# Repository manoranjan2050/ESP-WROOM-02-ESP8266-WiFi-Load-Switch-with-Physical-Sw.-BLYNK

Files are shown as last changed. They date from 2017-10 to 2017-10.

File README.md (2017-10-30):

# ESP-WROOM-02-ESP8266-WiFi-Load-Switch-with-Physical-Sw.-BLYNK
ESP8266 WiFi Mobile On-Off with Sync. Physical Sw. BLYNK App.

ESP-WROOM-02 BLYNK ONE Switch is a WiFi Load switch for Light Bulb, Fan, A/C etc. 
Synchronized Physical switch change button state on BLYNK server.

IMAGE ALT TEXT HERE (https://www.youtube.com/watch?v=g_l_Oe-BA2k) 

For instructions and setup. http://esp8266.signal.com.tr/

for PCB and PCBA Production https://www.pcbway.com/

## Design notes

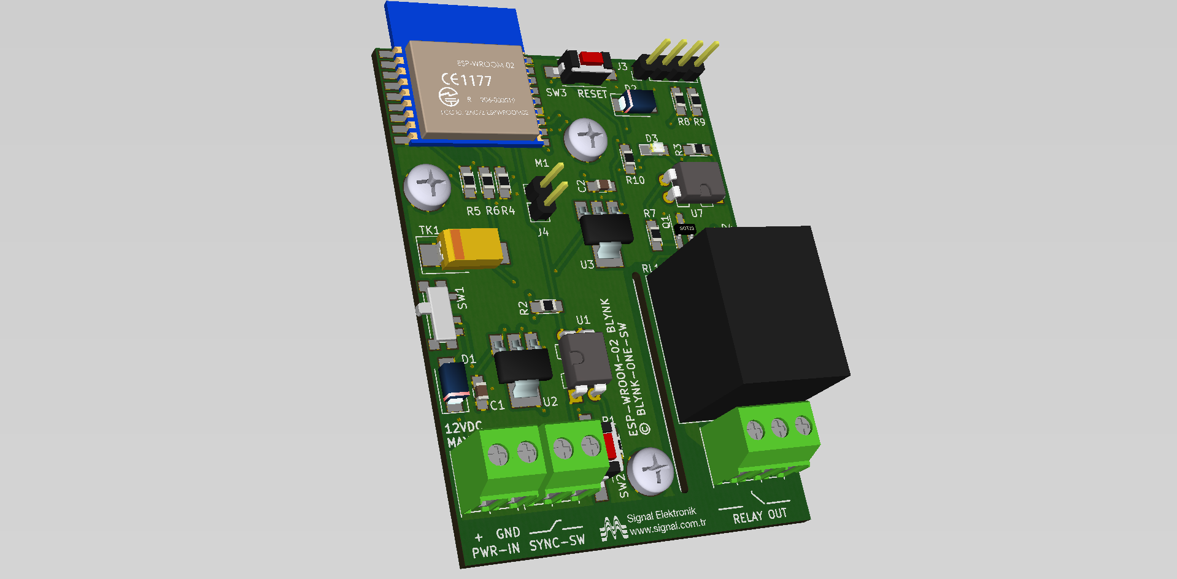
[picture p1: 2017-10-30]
esp-role-blynk/esp-relay-blynk.png

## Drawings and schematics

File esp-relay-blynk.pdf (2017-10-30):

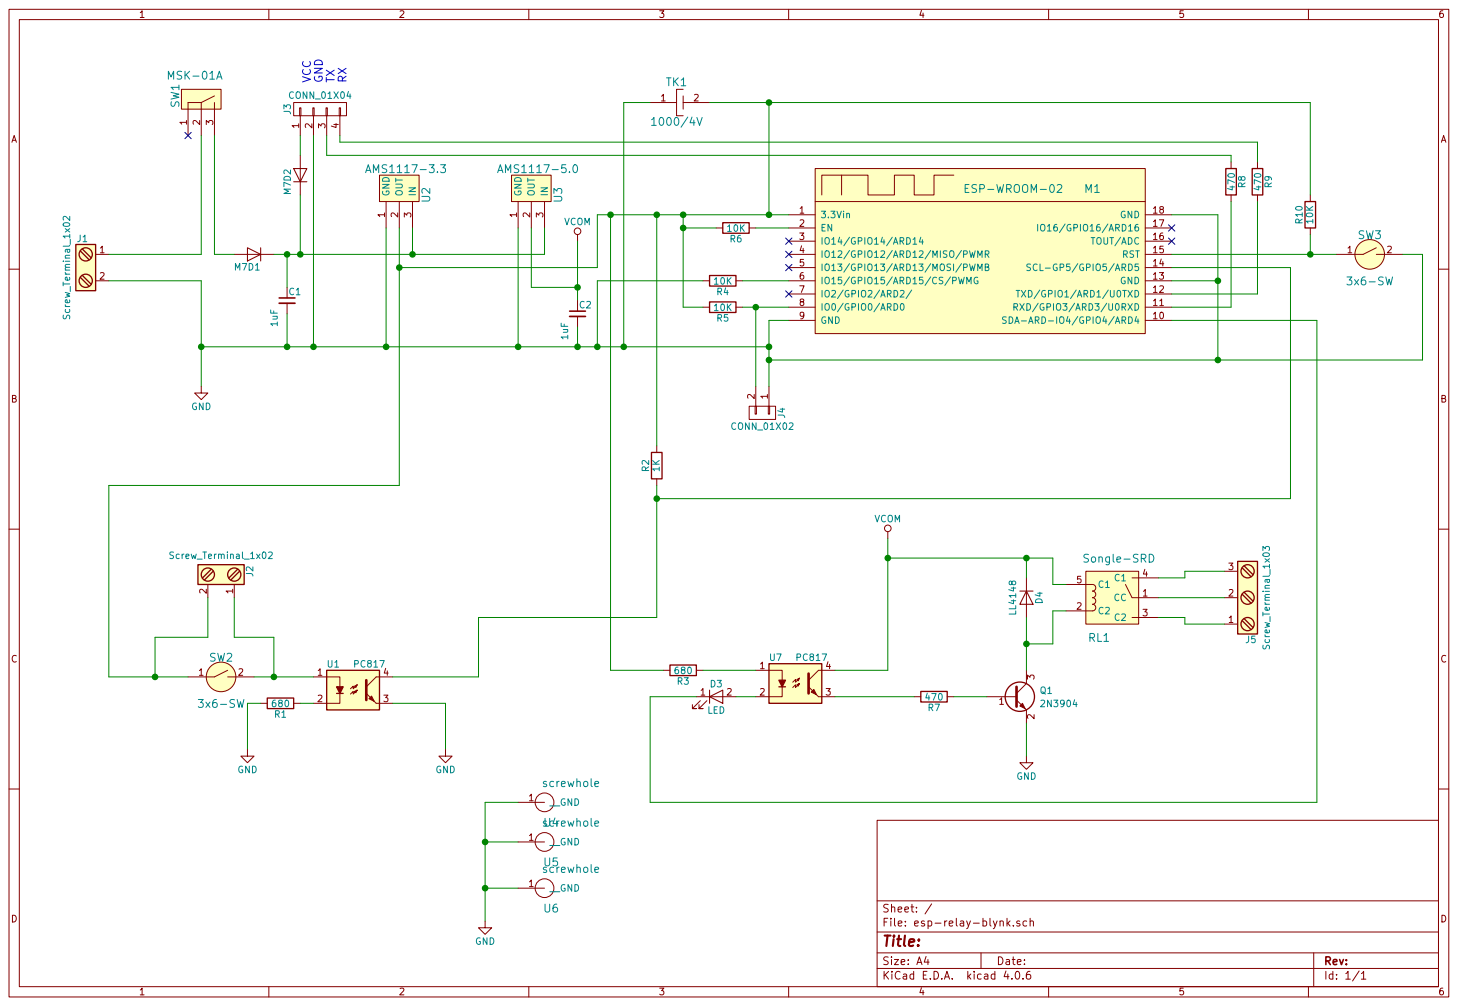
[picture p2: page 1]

1 J4 CONN_01X02 VCOM 470 R8 470 R9 CC 1 C2 2 C2 3 C1 4 C1 5 RL1 Songle-SRD

File: esp-relay-blynk.sch Sheet: /
Id: 1/1 Title:

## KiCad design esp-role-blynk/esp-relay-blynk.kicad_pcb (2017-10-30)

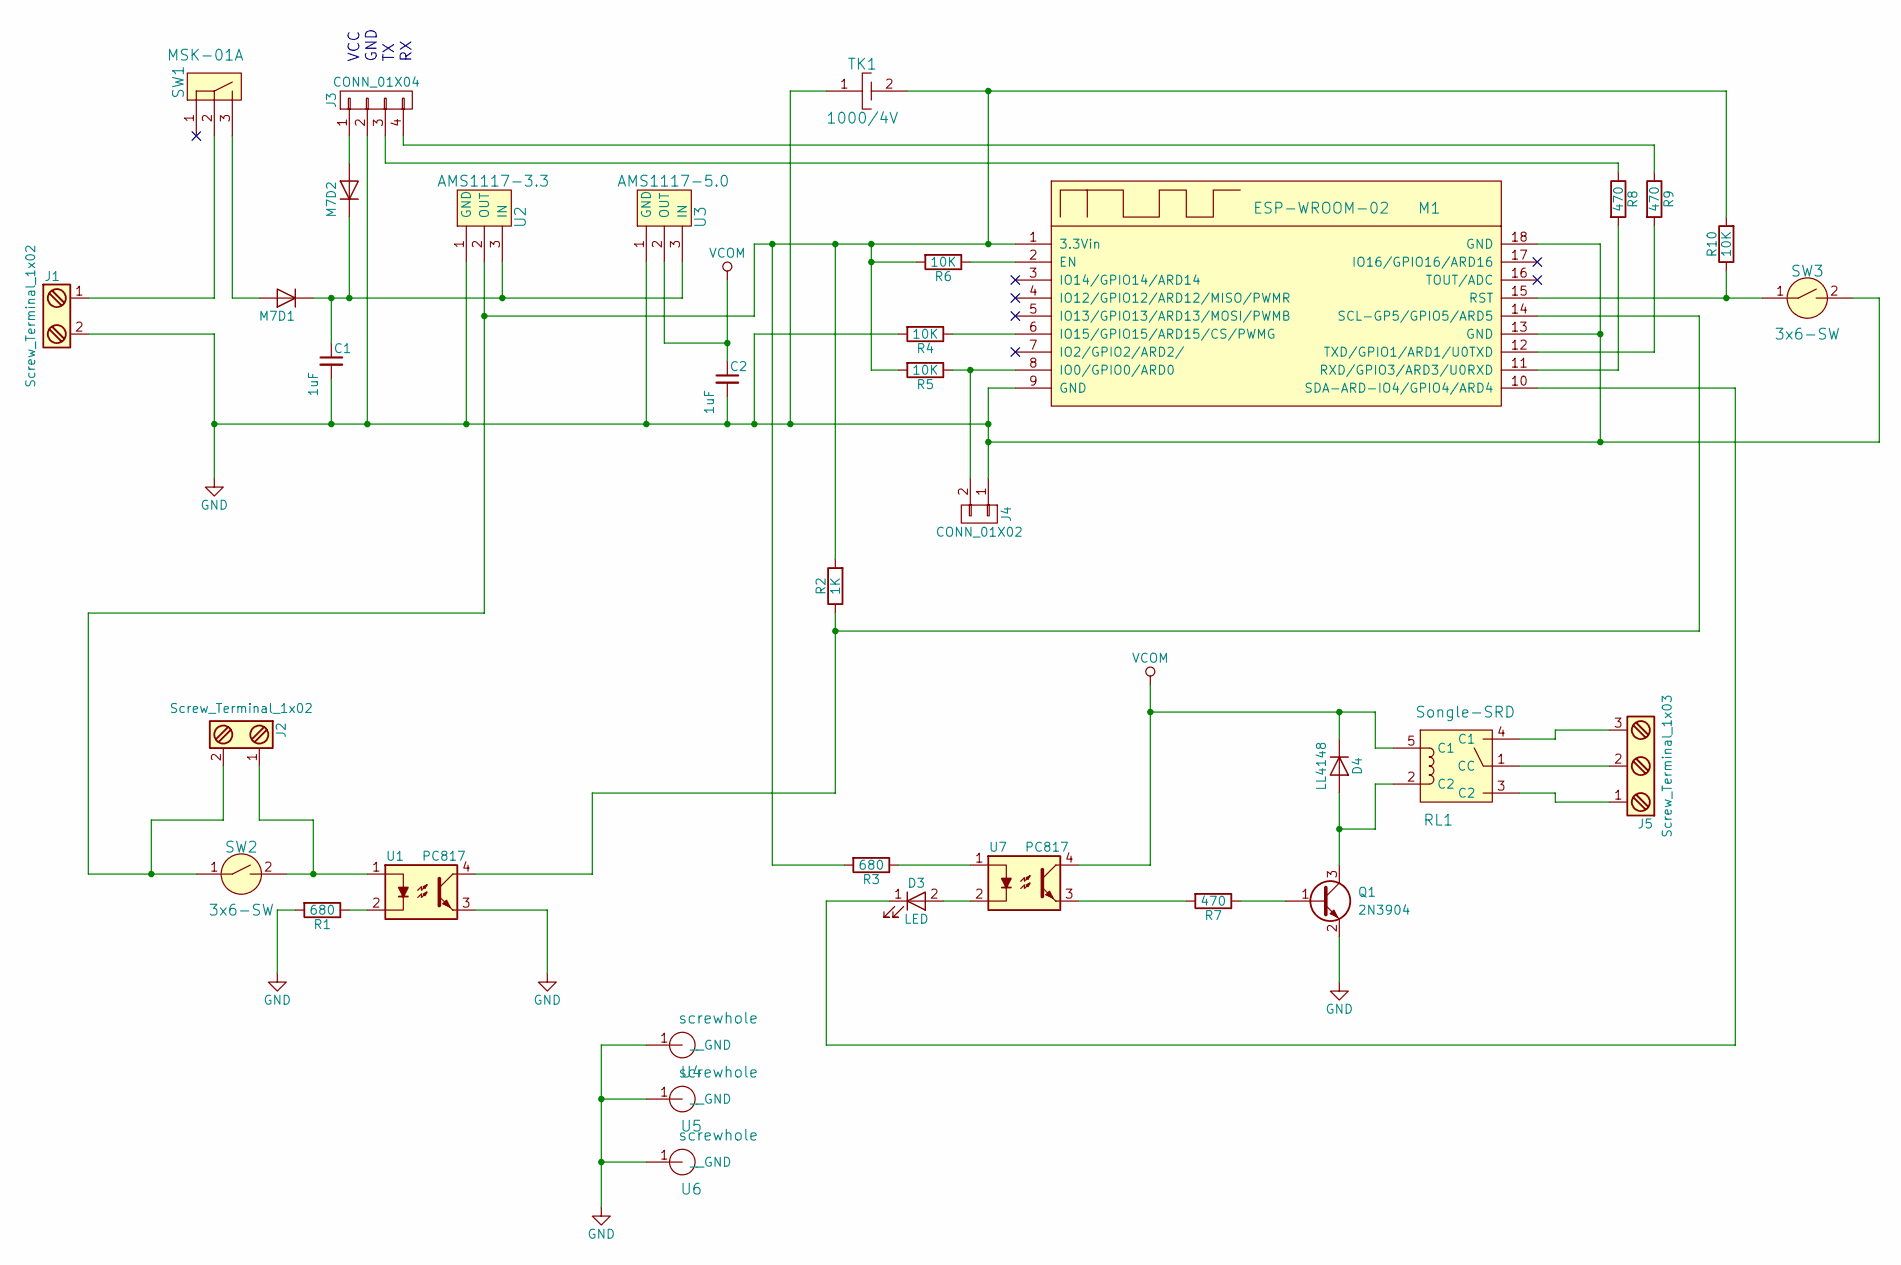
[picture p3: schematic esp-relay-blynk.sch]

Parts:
C1, C2: 1uF; C_0805_HandSoldering
D1, D2: M7; D_SMA
D3: LED; LED_0805_HandSoldering
D4: LL4148; D_MiniMELF
J1, J2: Screw_Terminal_1x02; TerminalBlock_Pheonix_PT-3.5mm_2pol
J3: CONN_01X04; Pin_Header_Straight_1x04_Pitch2.54mm
J4: CONN_01X02; Pin_Header_Straight_1x02_Pitch2.54mm
J5: Screw_Terminal_1x03; TerminalBlock_Pheonix_PT-3.5mm_3pol
M1: ESP-WROOM-02
Q1: 2N3904; SOT23HS
R1, R3: 680; R0805HS
R2: 1K; R0805HS
R4, R5, R6, R10: 10K; R0805HS
R7, R8, R9: 470; R0805HS
RL1: Songle-SRD
SW1: MSK-01A
SW2, SW3: 3x6-SW
TK1: 1000/4V; D-CASE-TK
U1, U7: PC817; DIP-4_W7.62mm
U2: AMS1117-3.3; SOT-223
U3: AMS1117-5.0; SOT-223
U4, U5, U6: screwhole; Screwhole

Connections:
GND: C1.2, C2.2, J1.2, J3.2, J4.1, M1.9 (GND), M1.13 (GND), M1.18 (GND), Q1.2 (E), R1.2, R4.2, SW3.2, TK1.1, U1.3, U2.1 (GND), U3.1 (GND), U4.1, U5.1, U6.1
unnamed: C1.1, D1.1 (K), D2.1 (K), U2.3 (IN), U3.3 (IN)
unnamed: D1.2 (A), SW1.3
unnamed: D2.2 (A), J3.1
unnamed: D3.1 (K), M1.10 (SDA-ARD-IO4/GPIO4/ARD4)
unnamed: D3.2 (A), U7.2
unnamed: D4.2 (A), Q1.3 (C), RL1.2 (C2)
unnamed: J1.1, SW1.2
unnamed: J2.1, SW2.2, U1.1
unnamed: J2.2, M1.1 (3.3Vin), R2.2, R3.2, R5.2, R6.2, R10.2, SW2.1, TK1.2, U2.2 (OUT)
unnamed: J3.3, R8.1
unnamed: J3.4, R9.1
unnamed: J4.2, M1.8 (IO0/GPIO0/ARD0), R5.1
unnamed: J5.1, RL1.3 (C2)
unnamed: J5.2, RL1.1 (CC)
unnamed: J5.3, RL1.4 (C1)
unnamed: M1.2 (EN), R6.1
unnamed: M1.6 (IO15/GPIO15/ARD15/CS/PWMG), R4.1
unnamed: M1.11 (RXD/GPIO3/ARD3/U0RXD), R8.2
unnamed: M1.12 (TXD/GPIO1/ARD1/U0TXD), R9.2
unnamed: M1.14 (SCL-GP5/GPIO5/ARD5), R2.1, U1.4
unnamed: M1.15 (RST), R10.1, SW3.1
unnamed: Q1.1 (B), R7.1
unnamed: R1.1, U1.2
unnamed: R3.1, U7.1
unnamed: R7.2, U7.3
VCOM: C2.1, D4.1 (K), RL1.5 (C1), U3.2 (OUT), U7.4

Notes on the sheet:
VCC GND TX RX

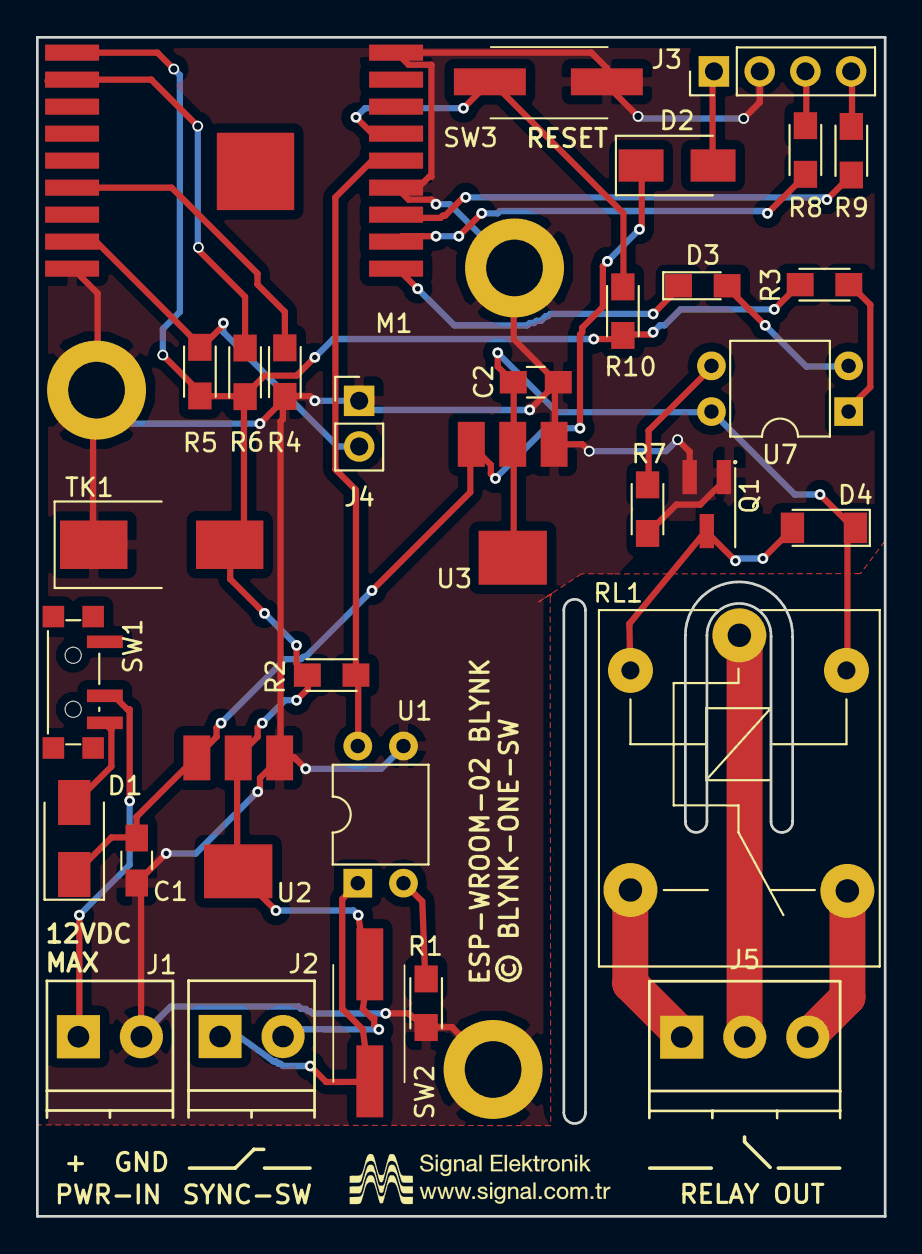
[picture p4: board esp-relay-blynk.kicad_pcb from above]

Board: 2 copper layers, 47.1 x 65.5 mm, 35 parts (0 on the bottom side), 27 nets.

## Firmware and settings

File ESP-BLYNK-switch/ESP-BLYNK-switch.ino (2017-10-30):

/* Comment this out to disable prints and save space */
#define BLYNK_PRINT Serial


#include <ESP8266WiFi.h>
#include <BlynkSimpleEsp8266.h>

// You should get Auth Token in the Blynk App.
// Go to the Project Settings (nut icon).
char auth[] = "YourAuthToken";

// Your WiFi credentials.
// Set password to "" for open networks.
char ssid[] = "YourNetworkName";
char pass[] = "YourPassword";

// Set your LED and physical button pins here
const int ledPin = 4;
const int btnPin = 5;

BlynkTimer timer;
void checkPhysicalButton();

int ledState = LOW;
int btnState = HIGH;

// Every time we connect to the cloud...
BLYNK_CONNECTED() {
  // Request the latest state from the server
  Blynk.syncVirtual(V3);

  // Alternatively, you could override server state using:
  //Blynk.virtualWrite(V3, ledState);
}

// When App button is pushed - switch the state
BLYNK_WRITE(V3) {
  ledState = param.asInt();
  digitalWrite(ledPin, ledState);
}

void checkPhysicalButton()
{
  if (digitalRead(btnPin) == LOW) {
    // btnState is used to avoid sequential toggles
    if (btnState != LOW) {

      // Toggle LED state
      ledState = !ledState;
      digitalWrite(ledPin, ledState);

      // Update Button Widget
      Blynk.virtualWrite(V3, ledState);
    }
    btnState = LOW;
  } else {
    btnState = HIGH;
  }
}

void setup()
{
  // Debug console
  Serial.begin(9600);

  Blynk.begin(auth, ssid, pass);
  // You can also specify server:
  //Blynk.begin(auth, ssid, pass, "blynk-cloud.com", 8442);
  //Blynk.begin(auth, ssid, pass, IPAddress(192,168,1,100), 8442);

  pinMode(ledPin, OUTPUT);
  pinMode(btnPin, INPUT_PULLUP);
  digitalWrite(ledPin, ledState);

  // Setup a function to be called every 100 ms
  timer.setInterval(100L, checkPhysicalButton);
}

void loop()
{
  Blynk.run();
  timer.run();
}

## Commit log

2017-10-30 PDF Schematics
    PDF Schematics added
2017-10-30 Create Gerber
2017-10-30 ESP-WROOM-02-ESP8266-WiFi-Load-Switch-with-Physical-Sw.-BLYNK
    Files
    [esp-relay-blynk-B.Cu.gbl, esp-relay-blynk-B.Mask.gbs, esp-relay-blynk-B.SilkS.gbo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]
2017-10-30 ESP-WROOM-02-ESP8266-WiFi-Load-Switch-with-Physical-Sw.-BLYNK
    Push
    [esp-relay-blynk.kicad_pcb, esp-relay-blynk.sch]

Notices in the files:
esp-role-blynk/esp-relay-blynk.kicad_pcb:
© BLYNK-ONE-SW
